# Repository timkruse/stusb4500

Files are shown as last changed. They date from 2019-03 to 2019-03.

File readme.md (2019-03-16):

# USB Type C Evaluation Board based on STUSB4500 by STM

This project implements the USB Type C connector based on the STM's STUSB4500 USB Power Delevery controller.
All signals are either routed to the dedicated USB connector or to an exteral connector to access signals such as I2C which is the config interface of the STUSB4500.  
The power lines are controled by FETs to suit the 100W specification of USB-C.

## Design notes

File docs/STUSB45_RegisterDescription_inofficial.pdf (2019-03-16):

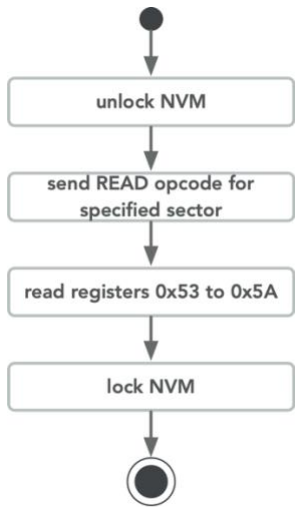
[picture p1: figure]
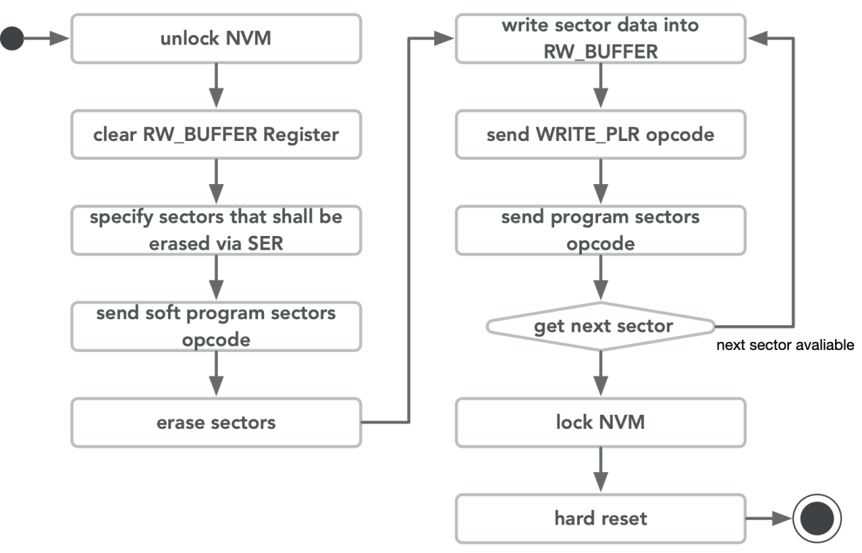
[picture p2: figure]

16.03.2019 | ©Tim-Hendrik Kruse | 1

# STUSB4500 Register Description

## 1 NVM Interface

The Non-Volatile Memory has an interface that is programmed via dedicated commands. The
commands are | configured | in | the | NVM_CTRL register (NVM_CTRL_LOW@0x96 and
NVM_CTRL_HIGH@0x97). The REQ bit makes the internal interface parse and execute the command. After the command has been executed it resets the REQ bit. Therefore it is important to first setup the high register of NVM_CTRL (0x97) and then write to the low register of NVM_CTRL (0x96).
The internal interface can be shut off and reset by dedicated bits in the NVM_CTRL register. While interfacing the NVM these bits have to be set to 1.

### 1.1 NVM Read Operation

Reading the NVM is done by sending the READ opcode along with the
specified sector. Afterwards the sector data can be read in the registers 0x53 to 0x5A.

Example command for reading out sector 2:

Configure the high byte of NVM_CTRL to the READ opcode: NVM_CTRL[15:8] = READ

Configure the low byte of NVM_CTRL with powering on the internals and un-reset it as well as sector 2 which shall be read:
NVM_CTRL[15:8] = (1 << PWR) | (1 << RST_N) | (1 << REQ) | 2

Wait until REQ bit is cleared and then read out registers 0x53 to 0x5A

### 1.2 NVM Write Operation

Before writing to a sector the sector has to be erased in advance.

STUSB4500 Register Description

### 1.3 Command Description

All commands require NVM_CTRL[7:6] to be 0b11.
Command | Dependency
READ | NVM_CTRL[2:0] – SECTOR specifying the respective sector (only 1 sector per command)

WRITE_PLR
WRITE_SER | NVM_CTRL[15:11] – SER_MASK each bit specifying 1 sector
READ_PLR
READ_SER
ERASE_SECTOR | -
PROG_SECTOR | NVM_CTRL[2:0] – SECTOR specifying the respective sector that will be programmed
SOFT_PROG_SECTOR | NVM_CTRL[15:11] – SER_MASK indicating which sectors will be available for reprogramming

### 1.4 Register Summary

Offset | Name | Bit Pos.
0x53 | NVM_RW_BUFF ER | 7:0 | RW_BUFFER[0]
0x54 | | 7:0 | RW_BUFFER[1]
0x55 | | 7:0 | RW_BUFFER[2]
0x56 | | 7:0 | RW_BUFFER[3]
0x57 | | 7:0 | RW_BUFFER[4]
0x58 | | 7:0 | RW_BUFFER[5]
0x59 | | 7:0 | RW_BUFFER[6]
0x5A | | 7:0 | RW_BUFFER[7]
0x95 | NVM_PASSWD | | PASSWORD
0x96 | NVM_CTRL | 7:0 | PWR | RST_N | REQ | SECTOR
0x97 | | 15:8 | SER_MASK | OPCODE
0xC0 | NVM Sector 0:0 | 7:0
0xC1 | NVM Sector 0:1 | 7:0
0xC2 | NVM Sector 0:2 | 7:0
0xC3 | NVM Sector 0:3 | 7:0
0xC4 | NVM Sector 0:4 | 7:0
0xC5 | NVM Sector 0:5 | 7:0
0xC6 | NVM Sector 0:6 | 7:0
0xC7 | NVM Sector 0:7 | 7:0
0xC8 | NVM Sector 1:0 | 7:0 | | | GPIO_CFG
0xC9 | NVM Sector 1:1 | 7:0 | | | VBUS_DI SCH_DIS ABLE
0xCA | NVM Sector 1:2 | 7:0
0xCB | NVM Sector 1:3 | 7:0
0xCC | NVM Sector 1:4 | 7:0
0xCD | NVM Sector 1:5 | 7:0
0xCE | NVM Sector 1:6 | 7:0
0xCF | NVM Sector 1:7 | 7:0
0xD0 | NVM Sector 2:0 | 7:0
0xD1 | NVM Sector 2:1 | 7:0
0xD2 | NVM sector 2:2 | 7:0
0xD3 | NVM Sector 2:3 | 7:0
0xD4 | NVM Sector 2:4 | 7:0
0xD5 | NVM Sector 2:5 | 7:0
0xD6 | NVM Sector 2:6 | 7:0
0xD7 | NVM Sector 2:7 | 7:0
0xD8 | NVM Sector 3:0 | 7:0
0xD9 | NVM Sector 3:1 | 7:0
0xDA | NVM Sector 3:2 | 7:0 | I_SNK_PDO1 | | | | SNK_UN CONS_P OWER | SNK_PDO_NUMB | | USB_CO MM_CA PABLE
0xDB | NVM Sector 3:3 | 7:0 | SHIFT_VBUS_HL1
0xDC | NVM Sector 3:4 | 7:0 | SHIFT_VBUS_LL2 | | | | I_SNK_PDO2
0xDD | NVM Sector 3:5 | 7:0 | I_SNK_PDO3 | | | | SHIFT_VBUS_HL2
0xDE | NVM Sector 3:6 | 7:0 | SHIFT_VBUS_HL3 | | | | SHIFT_VBUS_LL3
0xDF | NVM Sector 3:7 | 7:0
0xE0 | NVM Sector 4:0 | 7:0 | V_SNK_PDO2[1:0]
0xE1 | NVM Sector 4:1 | 7:0 | V_SNK_PDO2 [9:2]
0xE2 | NVM sector 4:2 | 7:0 | V_SNK_PDO23[7:0]
0xE3 | NVM Sector 4:3 | 7:0 | I_SNK_PDO_FLEX[5:0] | | | | | | V_SNK_PDO23[9:8]
0xE4 | NVM Sector 4:4 | 7:0 | | POWER_OK_CFG | | | I_SNK_PDO_FLEX[9:6]
0xE5 | NVM Sector 4:5 | 7:0
0xE6 | NVM Sector 4:6 | 7:0 | | | | REQ_SR C_CURR ENT | POWER_ ONLY_A BOVE_5 V
0xE7 | NVM Sector 4:7 | 7:0 | | Alarm Interrupt Mask

### 1.5 NVM Control Register

Name: | CTRL
Offset: | 0x96
Reset: | 0x0040
Property:
15 | 14 | 13 | 12 | 11 | 10 | 9 | 8
SER_MASK | | | | | OPCODE
RW | RW
7 | 6 | 5 | 4 | 3 | 2 | 1 | 0
PWR | RST_N | | REQ | | SECTOR
RW | RW | RW | RW

Bits 15:11 – SER_MASK[7:3]: Sector Erase Register Mask
For the OPCODEs WRITE_SER and ERASE_SECTOR the SER_MASK bits indicate which sectors are to be erased. There are five sectors each containing eight bytes. Each bit of SER_MASK specifies one sector.
First write the sector mask SER_MASK into SER via WRITE_SER opcode and then erase them via ERASE_SECTOR.

Bits 10:8 – OPCODE: Command to be executed
OPCODE | Value | Description
READ | 0 | Reads out one internal sector (0xC0 – 0xE7) specified by SECTOR and provides the values in RW_BUFFER (0x53-0x5A)
WRITE_PLR | 1 | Write Program Load Register (internally loads a program that enables the write to the NVM)
WRITE_SER | 2 | Write Sector Erase Register specified by SER_MASK
READ_PLR | 3 | Read Program Load Register
READ_SER | 4 | Read Sector Erase Register
ERASE_SECTOR | 5 | Erase sectors specified by SER_MASK
PROG_SECTOR | 6 | Program sector specified by SECTOR (requires an erase in advance)
SOFT_PROG_SECTOR | 7 | Soft program sectors specified by SER_MASK, so after erasing the sector it can be reprogrammed

BIT 7 – PWR
Powers on internal NVM circuitry to handle commands (unverified, best guess)

Bit 6 – RST_N
Enables internal NVM circuitry (unverified, best guess)
Active low.

Bit 4: REQ – Request command
Setting this bit triggers the chip to execute the OPCODE, so make sure to configure CTRL[15:8] firstly. When the chip is done executing the bit will be cleared.

Bits 2:0 SECTOR
Used by the READ and PROG_SECTOR opcodes to read the dedicated sector. Valid values are 0 to 4 meaning Sectors 0 to 4 respective.

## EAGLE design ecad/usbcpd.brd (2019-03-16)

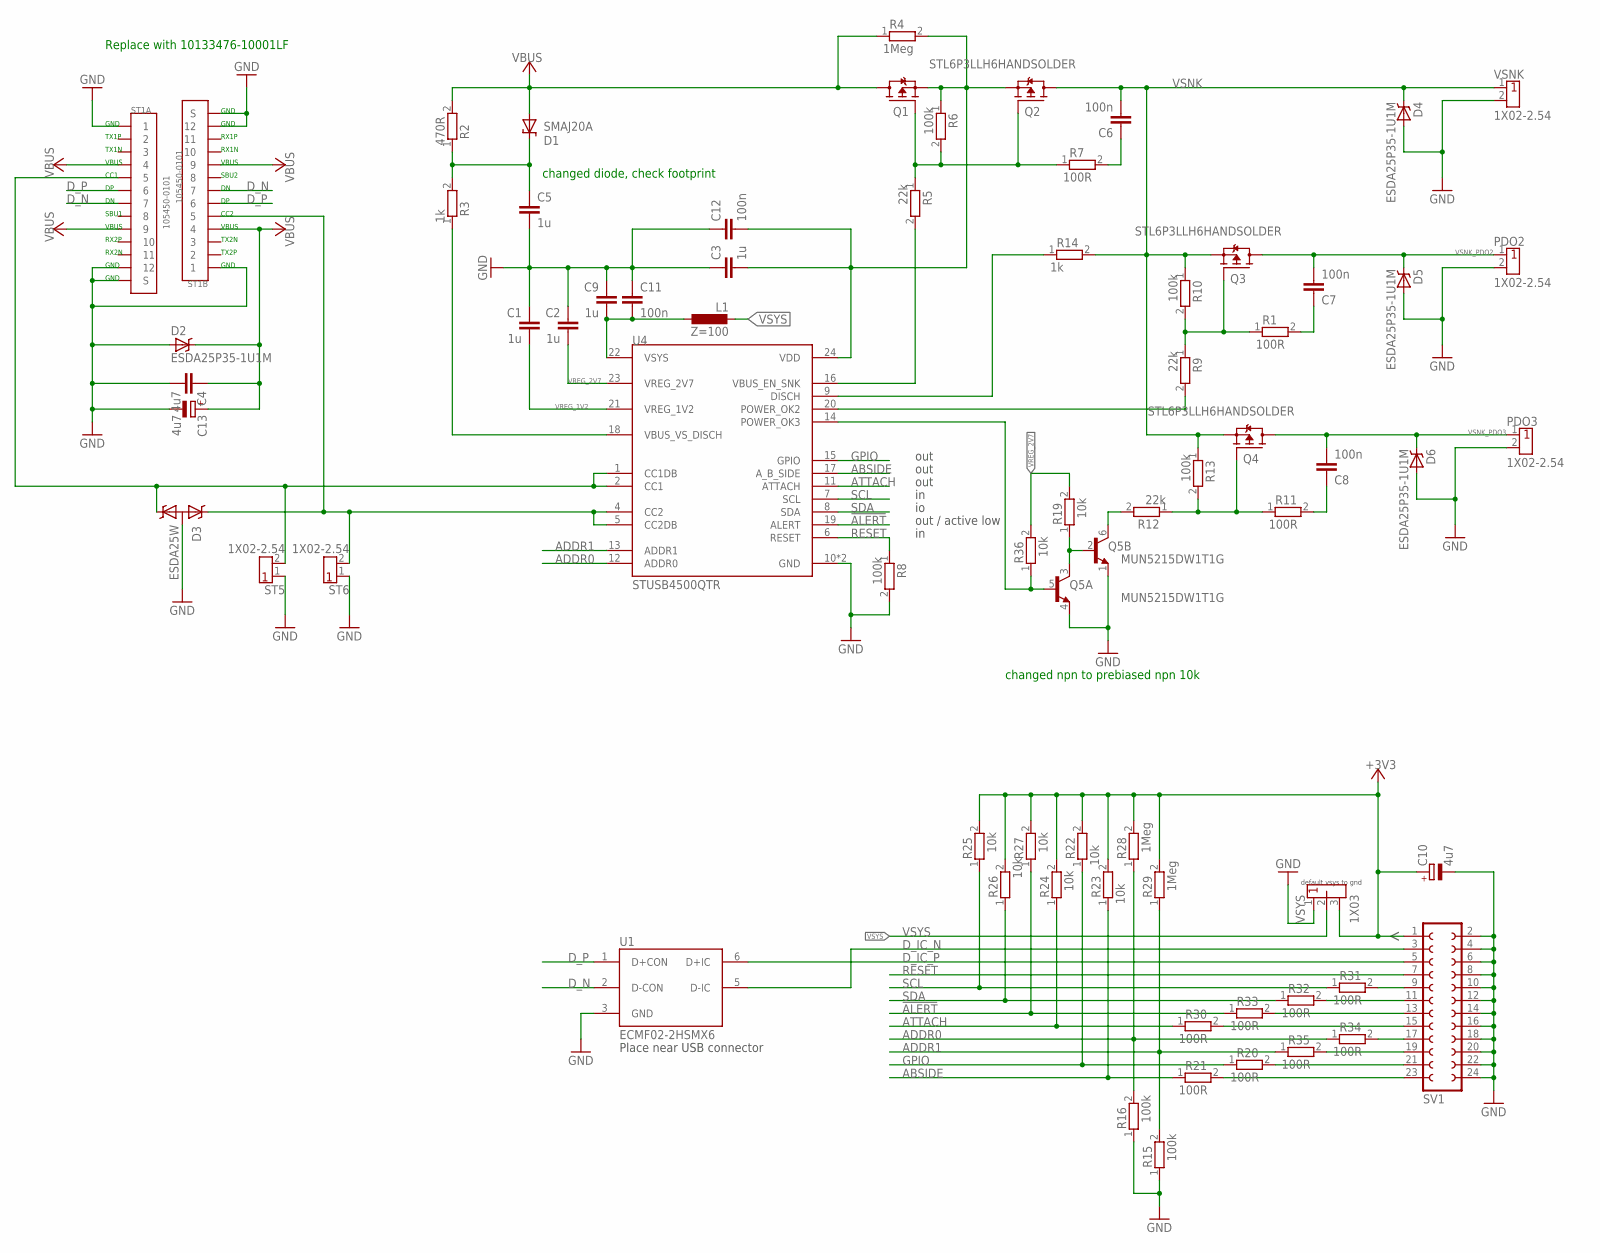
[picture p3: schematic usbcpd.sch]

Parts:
C1, C2, C3, C5, C9: 1u; 0805
C4: 4u7; 0805
C6, C7, C8, C11, C12: 100n; 0805
C10, C13: 4u7; E2-5
D1: SMAJ20A; SMBJ; MPN SMAJ20A
D2, D4, D5, D6: ESDA25P35-1U1M; QFN1610
D3: ESDA25W; SOT323-3
L1: Z=100; 0805; MPN MPZ2012S101AT000
PDO2, PDO3: 1X02-2.54
Q1, Q2, Q3, Q4: STL6P3LLH6HANDSOLDER; POWERFLAT-TYPEC-HANDSOLDER
Q5: MUN5215DW1T1G; SOT363; MPN MUN5215DW1T1G
R1, R7, R11, R20, R21, R30, R31, R32, R33, R34, R35: 100R; 0805
R2: 470R; 0805
R3, R14: 1k; 0805
R4, R28, R29: 1Meg; 0805
R5, R9, R12: 22k; 0805
R6, R8, R10, R13, R15, R16: 100k; 0805
R19, R22, R23, R24, R25, R26, R27, R36: 10k; 0805
ST1: 105450-0101
ST5, ST6: 1X02-2.54
SV1: FE12-2
U1: ECMF02-2HSMX6; UQFN6
U4: STUSB4500QTR; QFN24EP
VSNK: 1X02-2.54
VSYS: 1X03; 1X03-2.54

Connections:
!ALERT: R27.1, R33.1, U4.19 (ALERT)
+3V3: C10.+, R22.2, R23.2, R24.2, R25.2, R26.2, R27.2, R28.2, R29.2, SV1.1, VSYS.3
ABSIDE: R21.1, R23.1, U4.17 (A_B_SIDE)
ADDR0: R16.2, R28.1, R34.1, U4.12 (ADDR0)
ADDR1: R15.2, R29.1, R35.1, U4.13 (ADDR1)
ATTACH: R24.1, R30.1, U4.11 (ATTACH)
CC1: D3.2 (C2), ST1.A5 (5), ST5.2, U4.1 (CC1DB), U4.2 (CC1)
CC2: D3.1 (C1), ST1.B5 (5), ST6.2, U4.4 (CC2), U4.5 (CC2DB)
DISCH: R14.1, U4.9 (DISCH)
D_IC_N: SV1.3, U1.5 (D-IC)
D_IC_P: SV1.5, U1.6 (D+IC)
D_N: ST1.A7 (7), ST1.B7 (7), U1.2 (D-CON)
D_P: ST1.A6 (6), ST1.B6 (6), U1.1 (D+CON)
GND: C1.1, C2.1, C3.1, C4.2, C5.2, C9.1, C10.-, C11.1, C12.1, C13.-, D2.2 (A), D3.3 (A), D4.2 (A), D5.2 (A), D6.2 (A), PDO2.2, PDO3.2, Q5.1 (E), Q5.4 (E), R8.2, R15.1, R16.1, ST1.A1 (1), ST1.A12 (12), ST1.B1 (1), ST1.B12 (12), ST1.G1 (S), ST1.G2 (S), ST1.G3 (S), ST1.G4 (S), ST1.G5 (S), ST1.G6 (S), ST1.G7 (S), ST1.G8 (S), ST1.G9 (S), ST1.G10 (S), ST1.G11 (S), ST1.G12 (S), ST1.G13 (S), ST1.G14 (S), ST1.G15 (S), ST1.G16 (S), ST1.G17 (S), ST1.G18 (S), ST1.G19 (S), ST1.G20 (S), ST1.G21 (S), ST1.G22 (S), ST1.G23 (S), ST1.G24 (S), ST1.G25 (S), ST1.G26 (S), ST1.G27 (S), ST1.G28 (S), ST1.G29 (S), ST1.G30 (S), ST1.G31 (S), ST1.G32 (S), ST1.G33 (S), ST5.1, ST6.1, SV1.2, SV1.4, SV1.6, SV1.8, SV1.10, SV1.12, SV1.14, SV1.16, SV1.18, SV1.20, SV1.22, SV1.24, U1.3 (GND), U4.10 (GND), U4.TP (GND), VSNK.2, VSYS.1
GPIO: R20.1, R22.1, U4.15 (GPIO)
unnamed: C5.1, D1.C, R2.1, R3.2
unnamed: Q1.4 (G), Q2.4 (G), R5.1, R6.2, R7.1
unnamed: C6.1, R7.2
unnamed: C7.1, R1.2
unnamed: Q3.4 (G), R1.1, R9.1, R10.2
unnamed: C8.1, R11.2
unnamed: Q4.4 (G), R11.1, R12.1, R13.2
unnamed: R20.2, SV1.21
unnamed: R21.2, SV1.23
unnamed: R31.2, SV1.9
unnamed: R30.2, SV1.15
unnamed: R33.2, SV1.13
unnamed: R32.2, SV1.11
unnamed: R34.2, SV1.17
unnamed: R35.2, SV1.19
unnamed: C9.2, C11.2, L1.1, U4.22 (VSYS)
unnamed: Q5.2 (B), Q5.3 (C), R19.1
unnamed: Q5.6 (C), R12.2
PDO2: R9.2, U4.20 (POWER_OK2)
PDO3: Q5.5 (B), R36.1, U4.14 (POWER_OK3)
RESET: R8.1, SV1.7, U4.6 (RESET)
SCL: R25.1, R31.1, U4.7 (SCL)
SDA: R26.1, R32.1, U4.8 (SDA)
VBUS: C4.1, C13.+, D1.A, D2.1 (C), Q1.5 (D), R2.2, R4.1, ST1.A4 (4), ST1.A9 (9), ST1.B4 (4), ST1.B9 (9)
VBUS_EN_SNK: R5.2, U4.16 (VBUS_EN_SNK)
VBUS_VS_DISCH: R3.1, U4.18 (VBUS_VS_DISCH)
VDD: C3.2, C12.2, Q1.1 (S), Q1.2 (S), Q1.3 (S), Q2.1 (S), Q2.2 (S), Q2.3 (S), R4.2, R6.1, U4.24 (VDD)
VREG_1V2: C1.2, U4.21 (VREG_1V2)
VREG_2V7: C2.2, R19.2, R36.2, U4.23 (VREG_2V7)
VSNK: C6.2, D4.1 (C), Q2.5 (D), Q3.1 (S), Q3.2 (S), Q3.3 (S), Q4.1 (S), Q4.2 (S), Q4.3 (S), R10.1, R13.1, R14.2, VSNK.1
VSNK_PDO2: C7.2, D5.1 (C), PDO2.1, Q3.5 (D)
VSNK_PDO3: C8.2, D6.1 (C), PDO3.1, Q4.5 (D)
VSYS: L1.2, VSYS.2

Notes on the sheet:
GND
TX1P
TX1N
VBUS
CC1
CC2
SBU1
RX2P
RX2N
TX2N
TX2P
SBU2
RX1N
RX1P
Place near USB connector
out
out / active low
default vsys to gnd
changed npn to prebiased npn 10k
changed diode, check footprint
Replace with 10133476-10001LF

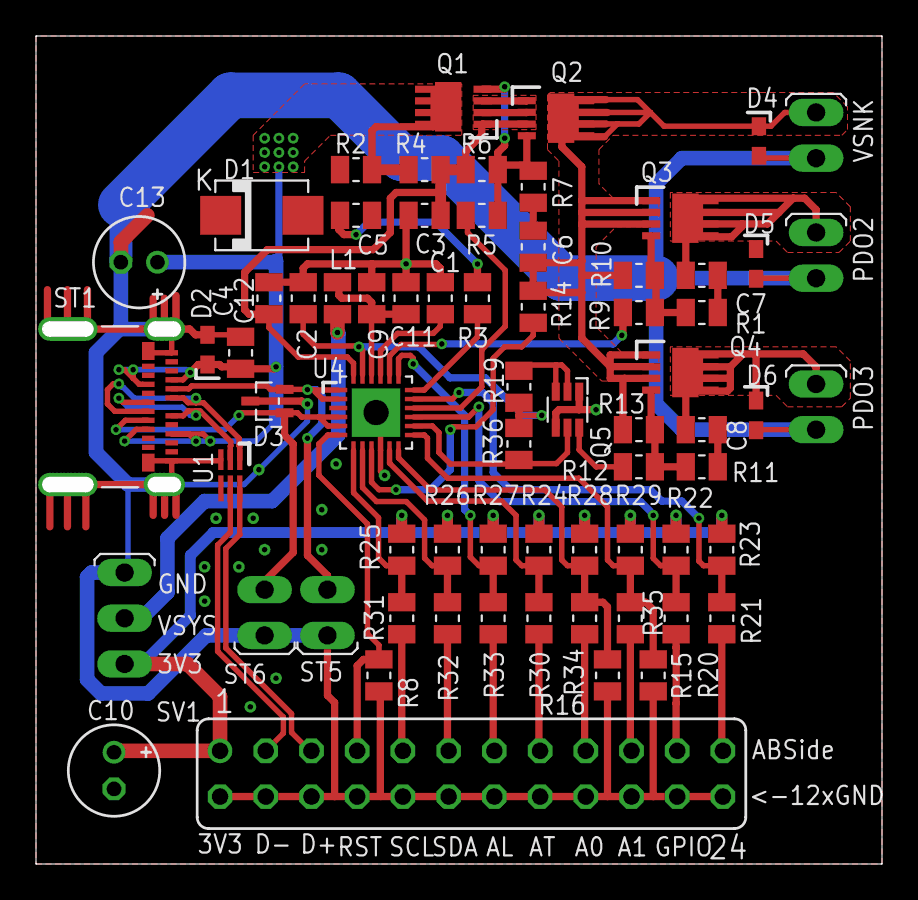
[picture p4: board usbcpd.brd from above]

Board: 2 copper layers, 47.0 x 46.0 mm, 69 parts (0 on the bottom side), 48 nets.

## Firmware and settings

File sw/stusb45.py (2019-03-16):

#!/usr/bin/env python2.7
from time import sleep
from collections import namedtuple
from smbus import SMBus
import RPi.GPIO as gpio

addr = 0x28 # I2C Address of the chip
bus = SMBus(1) # Raspi I2C bus

#	BCM-GPIO04 is on pin 7 of the header
reset_pin = 4
gpio.setmode(gpio.BCM)
gpio.setup(reset_pin, gpio.OUT)
def hard_reset():
	gpio.output(reset_pin, gpio.HIGH)
	sleep(0.2)
	gpio.output(reset_pin, gpio.LOW)


#	\brief Reads typec revision and usbpd revision of the chip
def version():
    BCD_TYPEC_REV_LOW = bus.read_byte_data(addr, 0x06)
    BCD_TYPEC_REV_HIGH = bus.read_byte_data(addr, 0x07)
    typec_rev = BCD_TYPEC_REV_HIGH << 8 | BCD_TYPEC_REV_LOW

    BCD_USBPD_REV_LOW = bus.read_byte_data(addr, 0x08)
    BCD_USBPD_REV_HIGH = bus.read_byte_data(addr, 0x09)
    usbpd_rev = BCD_USBPD_REV_HIGH << 8 | BCD_USBPD_REV_LOW
    Version = namedtuple("Version", "typec_rev, usbpd_rev")
    Version.__str__ = lambda v: "Version(typec_rev=" + hex(v.typec_rev) + ", usbpd_rev=" + hex(v.usbpd_rev)+ ")"
    Version.__repr__ = Version.__str__
	
    return Version(typec_rev=typec_rev, usbpd_rev=usbpd_rev)    

#	\brief Reads the current Status of the port (Sink-Source connection)
def port_status():
    PORT_STATUS_0 = bus.read_byte_data(addr, 0x0d)
    PORT_STATUS_1 = bus.read_byte_data(addr, 0x0e)

    attachedDeviceAsString = ["None", "Sink", "Source", "Debug Accessory", "Audio Accessory", "Power Accessory"]

    PortStatus = namedtuple("PortStatus", "stateChanged, attachedDevice, lowPowerStandby, powerMode, dataMode, attached")
    PortStatus.__str__ = lambda ps: "PortStatus(stateChanged=" + ("True" if ps.stateChanged == 1 else "False") + \
	", attachedDevice=" + (attachedDeviceAsString[ps.attachedDevice] if (ps.attachedDevice >= 0 and ps.attachedDevice <= 5) else "undefined(" + str(ps.attachedDevice) + ")") + \
	", lowPowerStandby=" +  ("standby mode" if ps.lowPowerStandby == 1 else "normal mode") + \
	", powerMode=" +  ("Source" if ps.powerMode == 1 else "Sink") + \
	", dataMode=" +  ("DFP" if ps.dataMode == 1 else "UFP") + \
	", attached=" +  ("True" if ps.attached == 1 else "False") + ")"
    PortStatus.__repr__ = PortStatus.__str__
    return PortStatus(stateChanged=PORT_STATUS_0 & 0x01, attachedDevice=PORT_STATUS_1 >> 5 & 0x07, lowPowerStandby=PORT_STATUS_1 >> 4 & 0x01, powerMode=PORT_STATUS_1 >> 3 & 0x01, dataMode=PORT_STATUS_1 >> 2 & 0x01, attached=PORT_STATUS_1 & 0x01)

#	\brief Reads the currently active PDO contract
def active_contract():
	DPM_PDO_NUMB = bus.read_byte_data(addr, 0x70)
	PDO_Contract = namedtuple("PDO_Contract", "num")
	return PDO_Contract(num=DPM_PDO_NUMB & 3)

#	\brief Forces to use another PDO contract
#	The STUSB4500 offers 3 PDO contracts and take effect after a soft reset
#	\param newValue: New contract PDO1, PDO2 or PDO3
def set_active_contract(newValue):
	# this is the active pdo contract. This takes effect after a sw reset (if source has the capability of the configured pdo)
	if newValue >= 0 and newValue < 4:
		return bus.write_byte_data(addr, 0x70, newValue)

#	\brief Reads all currently configured PDOs from the chip
#	REQ_SRC_CURRENT == unconstrainedPower
def read_pdo():
	base_reg = 0x85
	bvalues = [] # byte values
	for reg in range(0x85, 0x91):
		bvalues.append(bus.read_byte_data(addr, reg))
	
	supplyStr = ["Fixed", "Variable", "Battery"]

	PdoSinkFix = namedtuple("PdoSinkFix", "current, voltage, fastRoleReqCur, dualRoleData, usbCommunicationsCapable, unconstrainedPower, higherCapability, dualRolePower, supply, raw")
	PdoSinkFix.__str__ = lambda ps: "PdoSink("+ \
	"voltage=" + str(ps.voltage / 20.0) + "V" + \
	", current=" + str(ps.current / 100.0) + "A" + \
	", fastRoleReqCur=" + str(ps.fastRoleReqCur) + \
	", dualRoleData=" + str(ps.dualRoleData) + \
	", usbCommunicationsCapable=" + str(ps.usbCommunicationsCapable) + \
	", unconstrainedPower=" + str(ps.unconstrainedPower) + \
	", higherCapability=" + str(ps.higherCapability) + \
	", dualRolePower=" + str(ps.dualRolePower) + \
	", supply=" + (supplyStr[ps.supply] if ps.supply >= 0 and ps.supply < 3 else "Undefined") + \
	", raw=0x" + format(ps.raw, '08x') + \
	")"
	PdoSinkFix.__repr__ = PdoSinkFix.__str__

	PdoSinkVar = namedtuple("PdoSinkVar", "min_voltage, max_voltage, current, supply, raw")
	PdoSinkVar.__str__ = lambda ps: "PdoSink("+\
	"voltage=[" + str(ps.min_voltage / 20.0) + "V-" + str(ps.max_voltage / 20.0) + "V]" + \
	", current=" + str(ps.current / 100.0) + "A" + \
	", supply=" + (supplyStr[ps.supply] if ps.supply >= 0 and ps.supply < 3 else "Undefined") + \
	", raw=0x" + format(ps.raw, '08x') + \
	")"
	PdoSinkVar.__repr__ = PdoSinkVar.__str__

	PdoSinkBat = namedtuple("PdoSinkBat", "min_voltage, max_voltage, power, supply, raw")
	PdoSinkBat.__str__ = lambda ps: "PdoSink("+\
	"voltage=[" + str(ps.min_voltage / 20.0) + "V-" + str(ps.max_voltage / 20.0) + "V]" + \
	", power=" + str(ps.power) + "W" + \
	", supply=" + (supplyStr[ps.supply] if ps.supply >= 0 and ps.supply < 3 else "Undefined") + \
	", raw=0x" + format(ps.raw, '08x') + \
	")"
	PdoSinkBat.__repr__ = PdoSinkBat.__str__
	
	pdo = {}
	for i in range(0, 3):
		reg = bvalues[i * 4 + 3] << 24 | bvalues[i * 4 + 2] << 16 | bvalues[i * 4 + 1] << 8 | bvalues[i * 4]
		supply = reg >> 30 & 0x3
		if supply == 0: #  fixed
			pdo[i+1] = PdoSinkFix(supply=supply, dualRolePower=reg>>29 & 0x1, higherCapability=reg>>28 & 0x1, unconstrainedPower=reg>>27 & 0x1, usbCommunicationsCapable=reg>>26 & 0x1, dualRoleData=reg>>25 & 0x1, fastRoleReqCur=reg>>23 & 0x3, voltage=reg>>10 & 0x3ff, current=reg & 0x3ff, raw=reg)
		elif supply == 1: # variable
			pdo[i+1] = PdoSinkVar(supply=supply, max_voltage=reg>>20 & 0x3ff, min_voltage=reg>>10 & 0x3ff, current=reg&0x3ff, raw=reg)
		elif supply == 2: # battery
			pdo[i+1] = PdoSinkBat(supply=supply, max_voltage=reg>>20 & 0x3ff, min_voltage=reg>>10 & 0x3ff, power=reg&0x3ff, raw=reg)
	return pdo

#	\brief Reads and then prints the Power Data Object
def print_pdo():
	for k, v in read_pdo().iteritems():
		print "PDO#" + str(k) + ": ", v
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
